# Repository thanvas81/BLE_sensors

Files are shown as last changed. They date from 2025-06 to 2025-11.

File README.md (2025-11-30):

BLE Sensor PCB – Project Repository

This repository contains all design files, documentation, and supporting materials for my BLE Sensor PCB Thesis.
It includes the hardware schematics, PCB layout, some example firmware, datasheets, and the final report/presentation.

📁 Repository Contents
🔧 BLE_sensors_pcb/

This folder contains the complete PCB design files, including:

Schematic

Board layout

These files represent the final hardware design for the BLE sensor module.

🧠 firmware/

This folder includes the early firmware code used to run the BLE sensor system.

📄 pdf_and_presentation/

This folder contains the final project documentation, including:

Project pdf

Slides / presentation

Thesis or final written report

This is the main reference for understanding the project goals, design, testing, and results.

📚 Datasheets/

Supporting datasheets for components used in the PCB design.

⚙️ .vscode/

Editor and workspace configuration files (for VS Code).

📘 Overview

This project focuses on developing a custom Bluetooth Low Energy sensor board for Indoor Tracking, including hardware design, embedded firmware, and full documentation of the development process.
The PCB, firmware, and final report together demonstrate the complete lifecycle of the system.

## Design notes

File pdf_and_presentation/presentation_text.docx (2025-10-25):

### Slide 1 — Cover

Καλημέρα σας, είμαι ο Βασίλογλου Αθανάσιος και σήμερα θα παρουσιάσω τη διπλωματική μου εργασία με τίτλο «Design of a Wireless Indoor Tracking System for Multi-Sensor Data Acquisition with BLE Channel Sounding», η οποία εκπονήθηκε στο ΕΜΠ υπό την επίβλεψη του καθηγητή κ. Χριστοφόρου.

### Slide 2 — Introduction (empty template in PPT, narrative needed)

Η ιδέα για την εν λόγω διπλωματική προέκυψε από ένα προβλημα που παρατήρησα καθημερινά στην δουλειά μου . Εργάζομαι στη BK Telematics σε μια εταιρεια η οποια ασχολείται κυρίως με συσκευές τηλεματικής επιτήρησης στόλου. Στην πράξη βλέπω καθημερινά ότι ενώ τα GPS/GNSS συστήματα λειτουργούν εξαιρετικά σε εξωτερικούς χώρους, καταρρέουν αμέσως μόλις βρεθούμε σε εσωτερικούς χώρους — είτε λόγω πλήρους απώλειας σήματος είτε λόγω έντονου multipath που οδηγεί σε δραματικά σφάλματα. Από αυτή τη διαπίστωση προήλθε και η ιδέα της εργασίας: να δημιουργήθεί μια λύση αντίστοιχης πρακτικότητας, αλλά λειτουργική σε indoor περιβάλλον. Στο πλαίσιο αυτό ανέπτυξα ένα χαμηλού κόστους και ενεργειακά αποδοτικό σύστημα που συνδυάζει indoor localization με multi-sensor data acquisition. Επελεξα BLE διότι είναι ήδη ευρέως διαθέσιμο, έχει χαμηλή κατανάλωση και με την εισαγωγή του Channel Sounding δίνει πρόσβαση σε( In-phase and quadrature) IQ-based μετρήσεις που επιτρέπουν sub-meter ακρίβεια χωρίς ειδικό hardware όπως άλλες γνωστές λύσεις πχ Ulta Wide band. Παράλληλα ενσωματώνονται περιβαλλοντικοί αισθητήρες και IMU ώστε ο κόμβος να μην είναι απλώς position tag αλλά context-aware monitoring μονάδα η οποία μπορεί να αξιοποιηθεί και ως ένα μέτρο ασφάλειας στον τομέα του industrial monitoring.

### Slide 3 — BLE Positioning Approaches

Οι BLE τεχνικές εντοπισμού μπορούν να ομαδοποιηθούν σε τρεις βασικές προσεγγίσεις.
Πρώτον, το RSSI-based localization, όπου η απόσταση εκτιμάται από τη στάθμη ισχύος του λαμβανόμενου σήματος. Είναι η απλούστερη μέθοδος, αλλά επηρεάζεται έντονα από multipath φαινόμενα με αποτέλεσμα περιορισμένη ακρίβεια με σφάλματα της τάξεως περίπου των 5 μέτρων . Δεύτερον, η μέθοδος AoA/AoD (Angle of Arrival/Departure), κατά την οποία χρησιμοποιούνται antenna arrays για να εξαχθεί η κατεύθυνση του σήματος. Η μέθοδος αυτή μπορεί να βελτιώσει σημαντικά την γεωμετρική επίλυση της θέσης ρίχνοντας την ακρίβεια περίπου στο 1 μέτρο , αλλά απαιτεί σύνθετο και ακριβό hardware. Η τελευταία μέθοδος είναι η χρήση του Channel Sounding, το οποίο εκμεταλλεύεται IQ-based μετρήσεις μέσω της ανακατασκευής της κρουστικης απόκρυσης του inverse fast fourier transform (IFFT) και μέσω Phase-Based Ranging .Με αυτους τους τρόπους η μέθοδος του chanel sounding καταφέρνει ναι εξαχθεί η απόσταση με sub-meter ακρίβεια, χωρίς την ανάγκη για array antennas. Στην παρούσα εργασία επιλέγεται η τρίτη προσέγγιση, επειδή προσφέρει τον καλύτερο συμβιβασμό ανάμεσα σε ακρίβεια και υλοποιήσιμη πολυπλοκότητα. Πάμε να αναλύσουμε εκτενέστες τους τρόπους υπολογισμού της απόστασης

### Slide 4 — IFFT Based Ranging

Στην περίπτωση του IFFT based ranging αξιοποιούμε το γεγονός ότι το κανάλι μετριέται σε διακριτές συχνότητες. Η κρουστική απόκριση αποτυπώνει τη χρονική δομή των πολλαπλών διαδρομών του σήματος καθως το σήμα φτάνει πολλαπλές φορές με διαφορετικές καθυστερήσεις και εντάσεις λόγω ανακλάσεων, σκέδασης κλπ. Η βασική ιδέα της μεθόδου είναι ότι το πρώτο ισχυρό peak στην κρουστικη αποκρυση CIR αντιστοιχεί στη συντομότερη φυσική διαδρομή – συνήθως την Line-of-Sight. Από τη χρονική καθυστέρηση τ του πρώτου peak εξάγουμε την απόσταση με d=c⋅τ,. Είναι σημαντικό να τονίσουμε ότι το resolution εξαρτάται από το συνολικό bandwidth και άρα σε BLE, που είναι narrowband, υπάρχει intrinsic limit στην χρονική διακριτική ικανότητα. Ωστόσο, σε περιβάλλον με LOS ή ήπιο multipath, η μέθοδος παραμένει σταθερή και χαμηλής διασποράς, κάτι που επιβεβαιώνεται στα πειραματικά αποτελέσματα αργότερα.

((

Όταν μετράς το κανάλι σε λίγο bandwidth, βλέπεις μόνο ένα “χοντρό” κομμάτι του φάσματος. Όταν κάνεις IFFT αυτού του περιορισμένου φάσματος, το αποτέλεσμα στο χρόνο είναι φαρδύ και δεν μπορείς να ξεχωρίσεις πολύ κοντινά multipath peaks — “μπερδεύονται” μεταξύ τους.

Με μεγάλο bandwidth έχεις πιο “λεπτομερή” γνώση του καναλιού στο frequency domain, άρα στο χρονικό domain η CIR γίνεται πιο αιχμηρή (με στενά peaks) και μπορείς να διακρίνεις πιο μικρές χρονικές διαφορές.

))

### Slide 5 — Phase Based Ranging

Στη περίπτωση του Phase-Based Ranging εκτιμούμε την απόσταση από το phase response του καναλιού στο πεδιο της συχνότητας. Ουσιαστικά η φάση ακολουθεί μια γραμμική σχέση με τη συχνότητα (της μορφής ϕ(f) ≈ −2πfd/c + ϕ0), και επομένως η κλίση αυτής της γραμμικής σχεσης μάς αποκαλύπτει την απόσταση. Το βασικό μειονέκτημα στην αντιμετώπιση της φάσης είναι ότι η μετρούμενη φάση είναι 2π wraping, δηλαδή το σύστημα “βλέπει” μόνο την υπόλοιπη τιμή μετά από κύλιση. Αυτό εισάγει αμφιβολια στον υπολογισμο της αποστασης γιατί πολλές διαφορετικές πραγματικές αποστάσεις δίνουν την ίδια τυλιγμένη φάση. Για να αρθεί αυτό το προβλημα αξιοποιείται multifrequency fitting: μετράμε δηαλδη τη φάση σε πολλαπλές συχνότητες και αναζητούμε τη γραμμική κλίση που εξηγεί με συνέπεια όλα τα wrapped δείγματα ταυτοχρόνως. Στην πράξη αυτό σημαίνει ότι εξετάζουμε όλες τις δυνατές “ξετυλιγμένες” εκδοχές (phase unwrapping hypotheses) για κάθε συχνότητα και βρίσκουμε εκείνη τη συνεπή λύση της μορφής που ελαχιστοποιεί το συνολικό σφάλμα fitting. Η ύπαρξη πολλαπλών συχνοτήτων σπάει το ambiguity που θα υπήρχε αν κοιτούσαμε μόνο μία συχνότητα, επειδή οι λάθος “λύσεις” δεν μπορούν να ευθυγραμμιστούν ταυτοχρόνως με γραμμική τάση σε όλο το σύνολο συχνοτήτων, ενώ η σωστή απόσταση παράγει συνεπή κλίση σε όλα τα σεναρια . Παρόλο που η μέθοδος είναι περισσότερο ευαίσθητη στο multipath σε σχέση με την IFFT, προσφέρει υψηλότερη θεωρητική ακρίβεια σε short-range σενάρια με καλή SNR και σταθερή φάση,

### Slide 6 — Hardware Design (Section title slide)

Σε αυτό το σημείο περνάμε από το θεωρητικό υπόβαθρο στην υλοποίηση. Το σύστημα που αναπτύχθηκε ενσωματώνει MCU με υποστήριξη BLE 6.0 αρα και Channel Sounding, υποσύστημα αισθητήρων, power management, και ενσύρματη διεπαφή UART–USB για debugging και data export. Η υλοποίηση έγινε σε 4-layer PCB με στόχο RF σταθερότητα, χαμηλό θόρυβο τοσο σε σήματα όσο και σε τροφοδοσία και συμπαγές αποτύπωμα, ώστε η σχεδίαση να είναι μεταφέρσιμη σε πραγματικές εφαρμογές και όχι απλώς εργαστηριακό πρωτότυπο.

### Slide 7 — PCB Stack Up

Eδώ παρατηρούμε το stack-up του PCB, στο οποίο το πρώτο inner layer λειτουργεί ως συνεχές ground plane για RF σταθερότητα και ελαχιστοποίηση επιστροφών, ενώ το δεύτερο inner layer χρησιμοποιείται ως dedicated power plane για τις 3V3 και 5V γραμμές. Τα εξωτερικά layers χρησιμοποιούνται για routing υψηλής πυκνότητας και τοποθέτηση εξαρτημάτων, με προσοχή στην τήρηση αποστάσεων από την RF περιοχή γύρω από το module. Επιπλέον, ο σχεδιασμός των σημάτων υψηλής ταχύτητας έγινε με καθαρές γραμμές (straight/continuous routing), αποφυγή περιττών vias και length/impedance matching στη διαφορική γραμμή USB ώστε να διατηρούνται οι προδιαγραφές signal integrity. Η εν λόγω δομή μειώνει τα ground discontinuities, περιορίζει EMI/EMC φαινόμενα και επιτρέπει αξιόπιστη λειτουργία υπό παρουσία έντονων χρονιστικών μεταβάσεων.

### Slide 8 — Schematic Diagram

Περνώντας στο πλήρες σχηματικό φαίνεται η ενσωμάτωση πέντε βασικών υποσυστημάτων: του ME54BS01 module με τον nRF54L15, του power subsystem (charger + buck-boost), των αισθητήρων (BME280 και IMU), του UART–USB bridge για διασύνδεση με host και των header για debug/flash. Στο επίπεδο του schematic δόθηκε έμφαση σε καθαρό διαχωρισμό των σήματων και σωστή αποσύζευξη στα κρίσιμα σημεία, ώστε να προετοιμαστεί ο layout χωρίς αλληλεπιδράσεις με το RF κομματι .

### Slide 9 — Power Supply (Part 1 — Battery & Charger)

Το power supply επιτρέπει διπλή τροφοδοσία — είτε από USB Type-C είτε από Li-ion μπαταρία. Ο charger (MCP73871 )αναλαμβάνει το charging με power-path management, διασφαλίζοντας ότι το σύστημα τροφοδοτείται ακόμη και κατά τη φόρτιση. Η διαχείριση αυτή είναι κρίσιμη καθώς μας επιτρέπει αδιάκοπη λειτουργία. Επιπλέον, δίνονται επιλογές θερμικής προστασίας και ρυθμιζόμενα charging profiles ώστε το subsystem να είναι robust στα πραγματικά deployment περιβάλλοντα.

Στο δεύτερο μέρος του power subsystem χρησιμοποιείται buck–boost converter (TPS63031) ώστε να παρέχεται σταθερά 3.3V ανεξάρτητα από το αν η είσοδος προέρχεται από USB στα 5V ή από Li-ion μπαταρία οπου κυμαίνεται 3.0–4.2V. Αυτό επιτρέπει αδιάλειπτη λειτουργία ακόμη και σε μεταβάσεις τροφοδοσίας. Εφαρμόστηκαν και decoupling πυκνωτές κοντά στις εισόδους/εξόδους για περιορισμό ripple. Η δομή με ξεχωριστά blocks (charger + regulator) δίνει modularity και, κυρίως, σαφή έλεγχο συμπεριφοράς σε κάθε “βημα¨ της τροφοδοσίας

### Slide 11 — UART – USB Bridge

Περνώντας στη uart usb bridge οπου χρησιοποιηθηκε κυρίως ως gateway για την ανάκτηση των δεδομέων περιβάλοντως και απόστασης βέπουμε πως χρησιμοποιήθηκε το MCP2221A που μεταφράζει UART frames σε USB αναγνωρίσιμο ως ένα virtual COM από το PC. Ο USB-C connector υλοποιήθηκε με CC biasing, ESD protection για προστασία. Η λύση αυτή επιτρέπει αξιόπιστο debug/logging και ταυτόχρονα διοχέτευση μετρήσεων χωρίς εξαρτήσεις από BLE,οποτε έχουμε ένα out-of-band αξιόπιστο control & export path.Ας περάσουμε τώρα στην υλοποίηση του λογισμικου.

### Slide 12 — Firmware Reflector (Flowchart)

Ξεκινώντας με το Το firmware του Reflector node βλέπουμε πως έχει κρατηθεί μια ξεκάθαρη δομήμε 3 task : αρχικά κανει ένα initialization των περιφερειακών και των αισθητήρων, και στη συνέχεια ππερνάει σε μια κατασταης αναμονής για Channel Sounding requests που προέρχονται από τον Initiator, αν λάβει μήνυμα εκίνηςης ξεκινά να «απανταει» πισω τα απαρίτητα μυνηματα για τον υπολογισμό της απόστασης στην μεριά του initiator . Παράλληλα εκτελεί περιοδικές μετρήσεις από BME280 και την τάση της μπαταρίας , τις τυποποιεί σε ένα sting μαζι με το id του reflector και τις δημοσιεύει μέσω BLE connectionless advertising. Η χρήση conection less advertising αντί σύνδεσης μειώνει latency και ενέργεια, επιτρέποντας scalable reception από πολλαπλούς anchors. Παράλλη έχει υλοποιηθεί μια ρουτίνα ελέγχου από την τελευταία κίνηση κατά την οποία αν περάσει ένα χρονικό διάσημα αδράνειας θέτει την συσκευή σε sleep mode για βελτιστη κατανάλωση ενεργιας

### Slide 13 — Initiator Firmware (Flowchart)

Ο Initiator είναι ο κόμβος που ελέγχει ενεργά την Channel Sounding διαδικασία. Ξεκινά με initialization Bluetooth stack και UART, και στη συνέχεια εκτελεί περιοδικά ranging sessions στέλνοντας καποαι ειδικά packets προς τον Reflector. Από την ανταλλαγή αυτή λαμβάνει IQ data και επεξεργάζεται σε πραγματικό χρόνο τα αποτελέσματα IFFT και Phase-Based Ranging για να εξάγει απόσταση. Ταυτόχρονα λειτουργεί ως gateway: λαμβάνοντας τα BLE advertisements από τον Reflector και προωθοντας τα μέσω UART στο host για logging και offline ανάλυση. Αυτή η αρχιτεκτονική απομονώνει τον υπολογισμό από τον φορητό κόμβο και κρατά τον Initiator ως σταθερό σημείο υψηλής αξιοπιστίας. Ας δούμε τωρα τα πειράματα και τα αποτελέσματα που εξάγαμε .

### Slide 14 — Results — First Testing Setup

Το πρώτο experimental setup αφορά ένα stepped–distance measurement σε ελεγχόμενο διάδρομο, ώστε να εξαχθεί ένα baseline error behavior των δύο μεθόδων (IFFT και Phase-Based Ranging). Σε κάθε βήμα κρατήθηκε σταθερή απόσταση και καταγράφηκαν πολλαπλές μετρήσεις για να εξαγουμε το average error.Το setup προσομοιώνει ρεαλιστική indoor LOS διάταξη, όπου multipath υπάρχει, αλλά όχι σε ακραίο βαθμό, επιτρέποντας καθαρή σύγκριση αλγορίθμων χωρίς υπερβολική παρεμβολή.Παρατηρούμε ότι σε αν δεν δεν υπήρξε έντονο mulitpath το PBR κατέληξε σε σημαντικά μεγαλύτερο error για αυτό για τις επόμενες μετρήσεις προτιμήθηκε η προσοχή να παραμείνει σον IFFT τροπο μετρησης. Παράληλα συνέχισα να λαμβάνω τα δεδομένα pbr με ανάλογο σφλαμα

### Slide 15 — Results — Second Testing Setup

Στο δεύτερο setup δοκιμάζεται μία πιο σύνθετη διάταξη one–initiator/one–reflector σε 2.7 m απόσταση, τοποθετημένα εκατέρωθεν διαδρόμου. Εδώ αξιολογείσα τη συμπεριφορά σε μεσαία απόσταση με πραγματικό multipath από τοίχους και πάτωμα καθως και τον εισαγώμενο θόρυβο λογο τις κίνησης ανθρωπων στον διάδρομο. Ο σκοπός δεν είναι μόνο το absolute error αλλά και η σταθερότητα στο χρόνο — δηλαδή πόσο “τρέμει” η εκτίμηση σε σταθερό geometry.Τα αποτελέσματα και πάλι μας έδωσαν πολύ χαμηλό estimation erro και σταθερό ως προς τον χρόνο και το ενναλασώμενο περιβάλλον

### Slide 16 — Results — Third Testing Setup

Στο τρίτο setup εξετάζεται πιο ρεαλιστικό περιβάλλον με ποικιλία αντικειμένων( ο χωρος ήταν κανονικά γεμάτος ) και αυξημένη ανακλαστικότητα, όπου το multipath γίνεται εντονότερο και στο εν λόγω παράδειγμα εξετάστικε και η ικανότητα του reflector να ανταπεξέλθει στα αιτήματα τριων initiator ταυτοχρονα . Το experiment αυτό δείχνει την συμπεριφορά του συστήματος σε ένα ρεαλιστικό περιβάλλον με διάφορους θορύβους και συνεχόμενη κίνηση ανθρωπων για να λάβουμε κάποια αποτελέσματα σε πιο ένα «ρεαλιστικό σενάριο» .

### Slide 17 — Results — Error Heat Map

Εδώ παρουσιάζεται ένα heat map του τοπικού error field γύρω από target περιοχή σε 1×1 m παράθυρο , με τα anchors σε σταθερή διάταξη. Το heat map αποκαλύπτει χωρική κατανομή σφάλματος, δείχνοντας ότι ο υπολογισμός της απόστασης παραμένει σε πολύ χαμηλά επίπεδα σφάλματος παρόλο την ταυτόχρονη εκτίμηση τριών initiator κρατώντατ το error σε επίπεδα κάτω των 0,2 μετρων

### Slide 18 — Conclusions and Perspectives

Συνολικά, αποδείχθηκε ότι το BLE Channel Sounding με IFFT-based εξαγωγή απόστασης μπορεί να επιτύχει sub-meter ακρίβεια σε indoor περιβάλλον χωρίς ειδικό hardware πέρα από BLE 6-ready modules, ενώ το Phase-Based Ranging λειτουργεί συμπληρωματικά αλλά είναι πιο ευαίσθητο και σε ένα θορυβόδες περιβάλλον η ακρίβεια του παραμένει κοντα στο ένα μετρο και λιγο απραπανω . Το σύστημα είναι modular, low-cost(15 ευρω ) και επιτρέπει κλιμάκωση προς multi-anchor positioning. Μελλοντικά, η εξέλιξη του project περιλαμβάνει (i) ανάπτυξη real-time supervision software, (ii) την μεταφορά σε ένα πιο scalable wireless gateway για συλλογή και διάθεση δεδομένων, , (iii) σχεδίαση στοχευμένου anchor/initiator hardware με ενίσχυση RF (βελτιστοποιημένη κεραία, PA/LNA front-end και dedicated RF layout) για μεγιστοποίηση εμβέλειας,καθως και στην περιπτωση που χρειαστει ένα πλήρως energy efficient μοντελο φια τον reflector αφαιρώντας κάποια στοιχεια όπως κάποια led , uart bridge κλτπ και τελευταιο θα μπορούσε να γίνει επέκταση των πειραμάτων προσθέτωντας έναν τέταρτο inititor γθα πλήρες 3D localization.

### Slide 19 — Thank you

Ευχαριστώ πολύ για τον χρόνο σας.

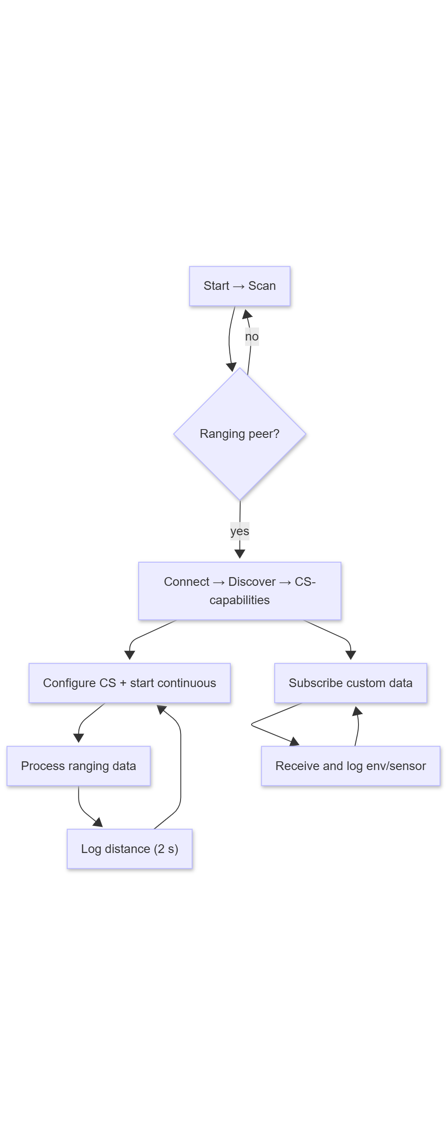
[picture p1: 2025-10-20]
pdf_and_presentation/ranging_data_logging.png

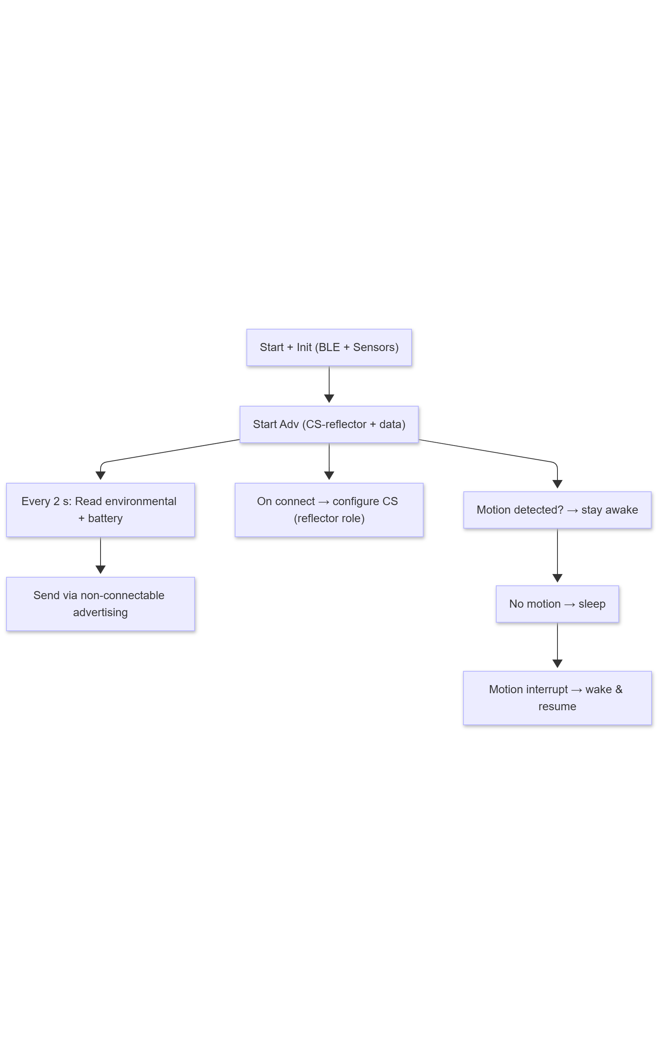
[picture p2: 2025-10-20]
pdf_and_presentation/ble_sensor_advertising.png

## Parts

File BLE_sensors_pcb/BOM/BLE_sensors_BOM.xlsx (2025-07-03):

Reference | Qty | Value | Footprint | Ordered | Status
C1, C2, C3, C4, C6, C11, C14, C16 | 8 | 0.1u | Capacitor_SMD:C_0603_1608Metric
C5, C10, C12, C13 | 4 | 10u | Capacitor_SMD:C_0805_2012Metric
C7, C8 | 2 | 4.7u | Capacitor_SMD:C_0603_1608Metric
C9 | 1 | 10u | Capacitor_SMD:C_0603_1608Metric
C17 | 1 | 4.7u | Capacitor_SMD:C_0805_2012Metric
D1, D2, D3 | 3 | LED | LED_SMD:LED_0603_1608Metric | OK
D4 | 1 | PRTR5V0U2X | Package_TO_SOT_SMD:SOT-143 | OK
J2 | 1 | Conn_01x02 | Connector_PinHeader_1.27mm:PinHeader_1x02_P1.27mm_Vertical
J3 | 1 | USB_C_Receptacle | Connector_USB:USB_C_Receptacle_G-Switch_GT-USB-7010ASV | GT-USB-7010ASV ?
L1 | 1 | 1.5u | Inductor_SMD:L_1210_3225Metric
R1, R2 | 2 | 4.7k | Resistor_SMD:R_0603_1608Metric
R3 | 1 | Rprog1 | Resistor_SMD:R_0603_1608Metric
R4 | 1 | Rprog3 | Resistor_SMD:R_0603_1608Metric
R5, R6, R7 | 3 | 470R | Resistor_SMD:R_0603_1608Metric
R8, R9 | 2 | 22R | Resistor_SMD:R_0603_1608Metric
R10, R14 | 2 | 100k | Resistor_SMD:R_0603_1608Metric
R11, R12 | 2 | 5.11k | Resistor_SMD:R_0603_1608Metric
R13 | 1 | 1M | Resistor_SMD:R_0603_1608Metric
R15, R16 | 2 | 100R | Resistor_SMD:R_0603_1608Metric
R17, R18, R19, TH1 | 4 | 10k | Resistor_SMD:R_0603_1608Metric
U1 | 1 | BME280 | Package_LGA:Bosch_LGA-8_2.5x2.5mm_P0.65mm_ClockwisePinNumbering | OK
U2 | 1 | LSM303AHTR | My_Libraries:LSM303AHTR | OK
U3 | 1 | TPS63031DSK | Package_SON:WSON-10-1EP_2.5x2.5mm_P0.5mm_EP1.2x2mm | OK
U4 | 1 | ME54BS01 | My_Libraries:ME54BS01 | OK | OK
U5 | 1 | MCP73871 | Package_DFN_QFN:QFN-20-1EP_4x4mm_P0.5mm_EP2.5x2.5mm | OK
U7 | 1 | MCP2221AxST | Package_SO:TSSOP-14_4.4x5mm_P0.65mm | ΟΚ

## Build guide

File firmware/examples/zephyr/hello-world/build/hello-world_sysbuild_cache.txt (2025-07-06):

APPLICATION_BINARY_DIR:PATH=C:/Users/Asus/Desktop/Files/School/Thesis/blecon-device-sdk/examples/zephyr/hello-world/build
APPLICATION_SOURCE_DIR:PATH=C:/ncs/v2.9.1/zephyr/share/sysbuild/template
APP_DIR:PATH=c:/Users/Asus/Desktop/Files/School/Thesis/blecon-device-sdk/examples/zephyr/hello-world
BOARD_DIR:PATH=C:/Users/Asus/Desktop/Files/School/Thesis/blecon-device-sdk/examples/zephyr/boards/minew/minew_me54be01/boards/minew/minew_me54be01
BOARD_DIRECTORIES:INTERNAL=C:/Users/Asus/Desktop/Files/School/Thesis/blecon-device-sdk/examples/zephyr/boards/minew/minew_me54be01/boards/minew/minew_me54be01
BOARD_EXTENSIONS:BOOL=ON
BOARD_ROOT:PATH=C:/Users/Asus/Desktop/Files/School/Thesis/blecon-device-sdk/examples/zephyr/boards/minew/minew_me54be01;C:/test/blinky_pwm
CACHED_BOARD:STRING=minew_me54be01/nrf54l15/cpuapp
CACHED_SHIELD:STRING=
FIND_PACKAGE_MESSAGE_DETAILS_Python3:INTERNAL=[C:/ncs/toolchains/0b393f9e1b/opt/bin/python.exe][cfound components: Interpreter ][v3.12.4(3.8)]
HWM:INTERNAL=v2
HWMv2:INTERNAL=True
NCS_TOOLCHAIN_VERSION:UNINITIALIZED=NONE
WEST:INTERNAL=C:/ncs/toolchains/0b393f9e1b/opt/bin/python.exe;-m;west
WEST_PYTHON:UNINITIALIZED=C:/ncs/toolchains/0b393f9e1b/opt/bin/python.exe
ZEPHYR_BASE:PATH=C:/ncs/v2.9.1/zephyr
Zephyr_DIR:PATH=C:/ncs/v2.9.1/zephyr/share/zephyr-package/cmake
_Python3_EXECUTABLE:INTERNAL=C:/ncs/toolchains/0b393f9e1b/opt/bin/python.exe
_Python3_INTERPRETER_PROPERTIES:INTERNAL=Python;3;12;4;64;;cp312-win_amd64;C:\ncs\toolchains\0b393f9e1b\opt\bin\Lib;C:\ncs\toolchains\0b393f9e1b\opt\bin\Lib;C:\ncs\toolchains\0b393f9e1b\opt\bin\Lib\site-packages;C:\ncs\toolchains\0b393f9e1b\opt\bin\Lib\site-packages
_Python3_INTERPRETER_SIGNATURE:INTERNAL=789456af6c61fc011023bd90a8135e32
sysbuild_toplevel_BINARY_DIR:STATIC=C:/Users/Asus/Desktop/Files/School/Thesis/blecon-device-sdk/examples/zephyr/hello-world/build
sysbuild_toplevel_IS_TOP_LEVEL:STATIC=ON
sysbuild_toplevel_SOURCE_DIR:STATIC=C:/ncs/v2.9.1/zephyr/share/sysbuild
BOARD:STRING=minew_me54be01/nrf54l15/cpuapp
SYSBUILD_NAME:STRING=hello-world
SYSBUILD_MAIN_APP:BOOL=True

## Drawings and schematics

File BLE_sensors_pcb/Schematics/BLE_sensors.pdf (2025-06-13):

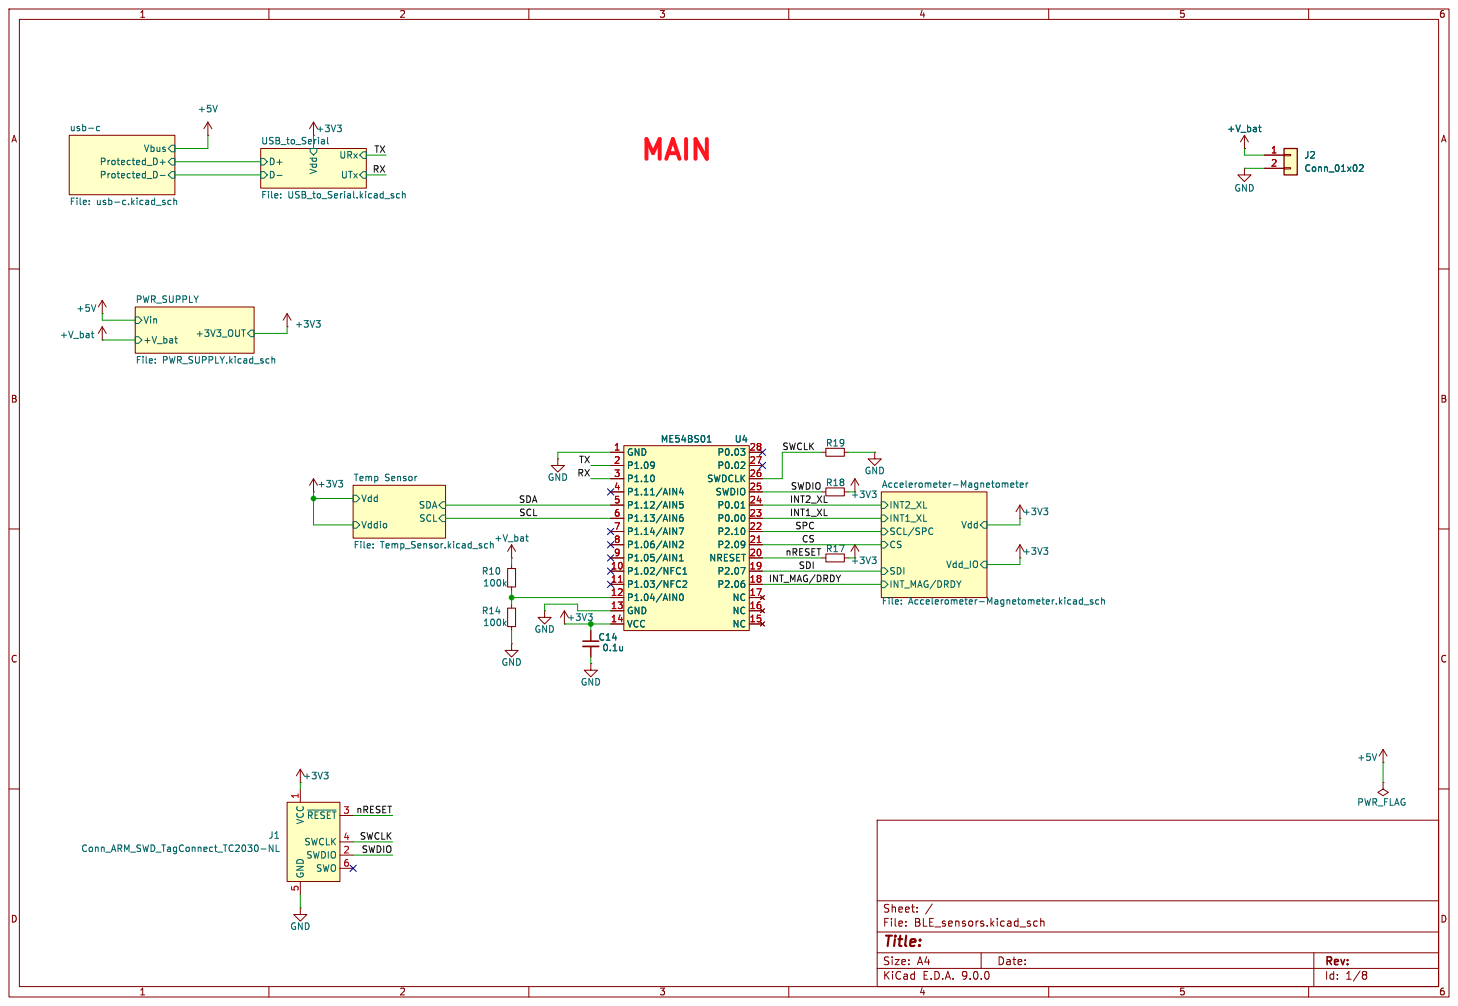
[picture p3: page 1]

Accelerometer-Magnetometer File: Accelerometer-Magnetometer.kicad_sch GND

5 ~{RESET}3 SWCLK 4 SWDIO 2 SWO 6

Id: 1/8 Title: File: BLE_sensors.kicad_sch Sheet: /

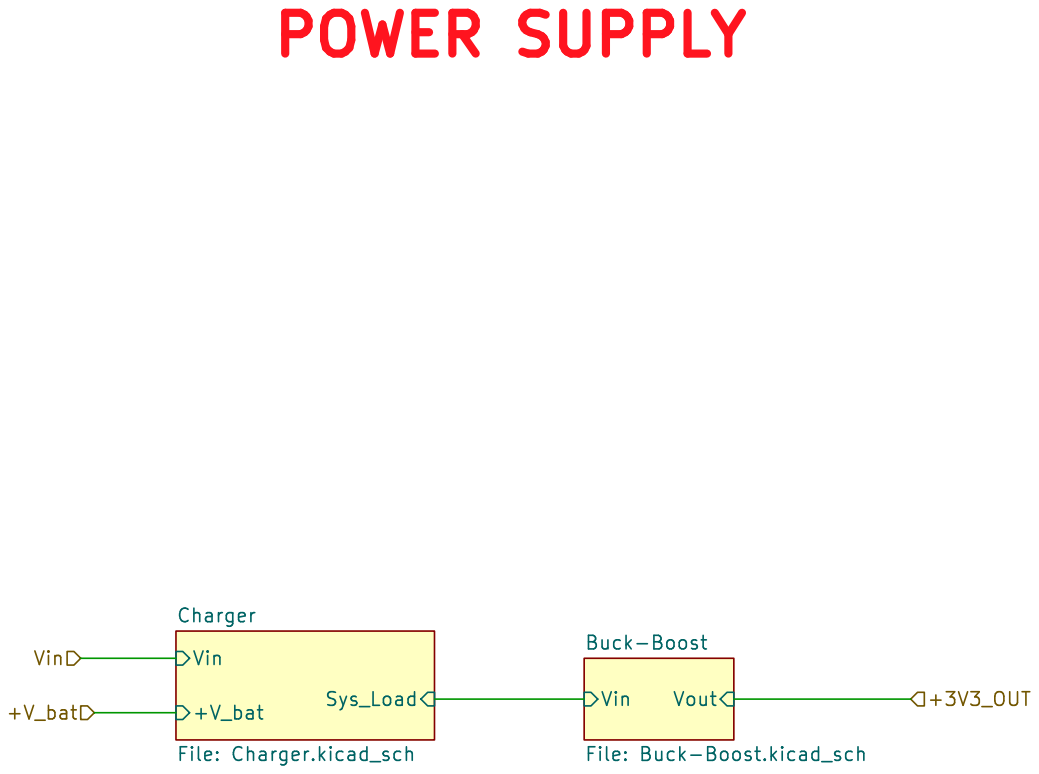
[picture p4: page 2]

Id: 2/8 Title: Charger File: PWR_SUPPLY.kicad_sch Sheet: /PWR_SUPPLY/

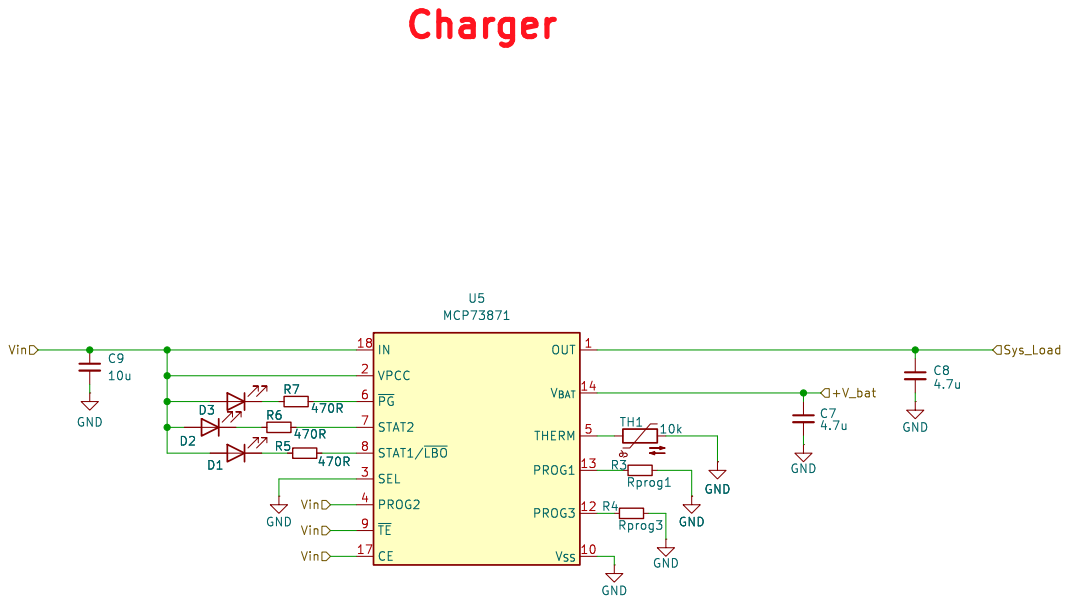
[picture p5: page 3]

Id: 3/8 Title: Charger File: Charger.kicad_sch Sheet: /PWR_SUPPLY/Charger/

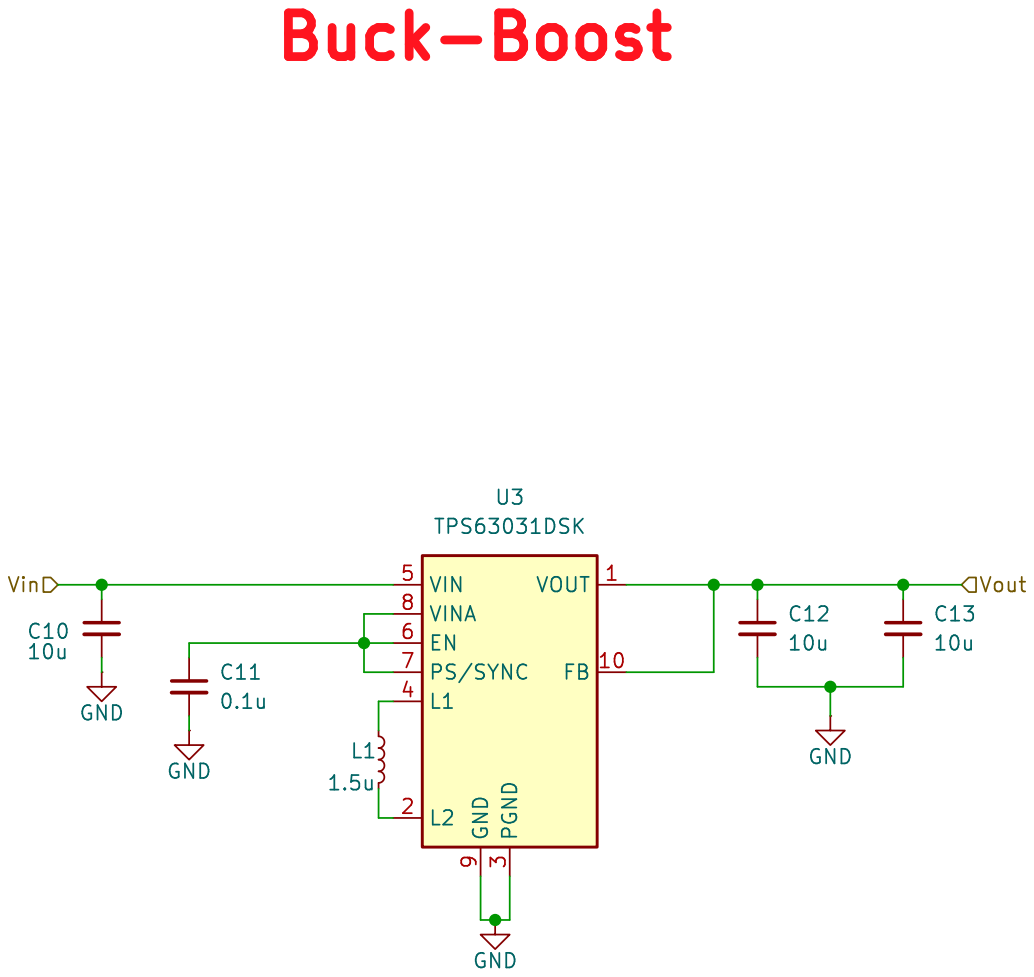
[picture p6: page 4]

Id: 4/8 Title: File: Buck-Boost.kicad_sch Sheet: /PWR_SUPPLY/Buck-Boost/

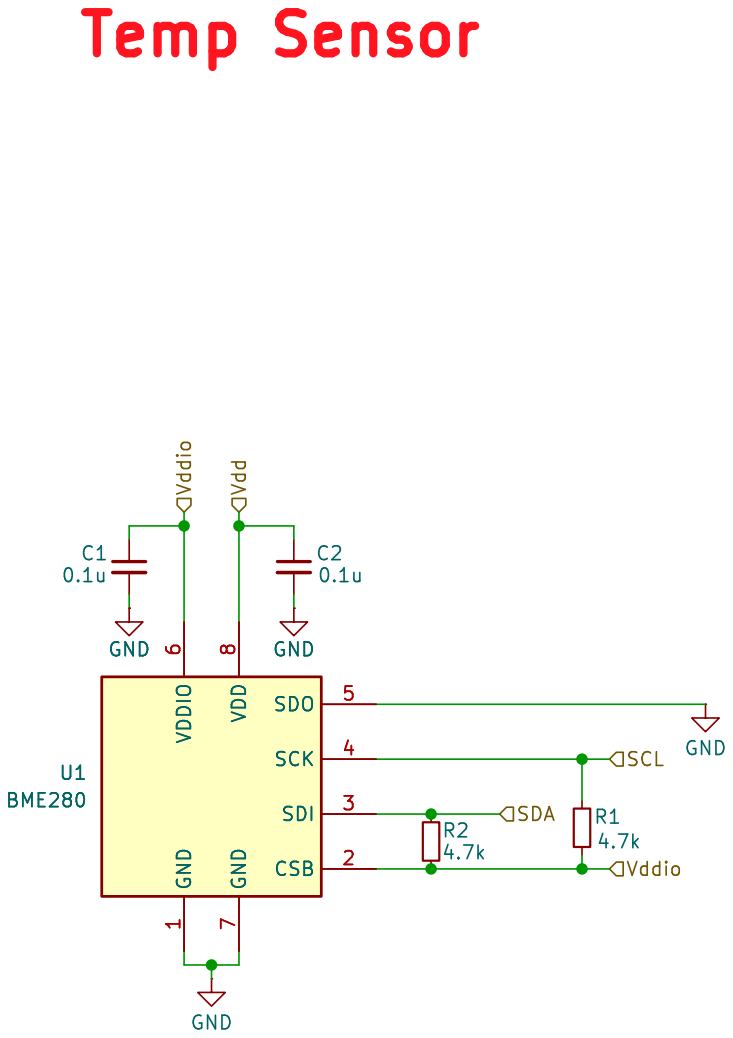
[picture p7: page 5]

7 SDO 5 SCK 4 SDI 3 CSB 2 U1 BME280 C2
0.1u GND

7 SDO 5 SCK 4 SDI 3 CSB 2 GND GND
4.7k VDDIO

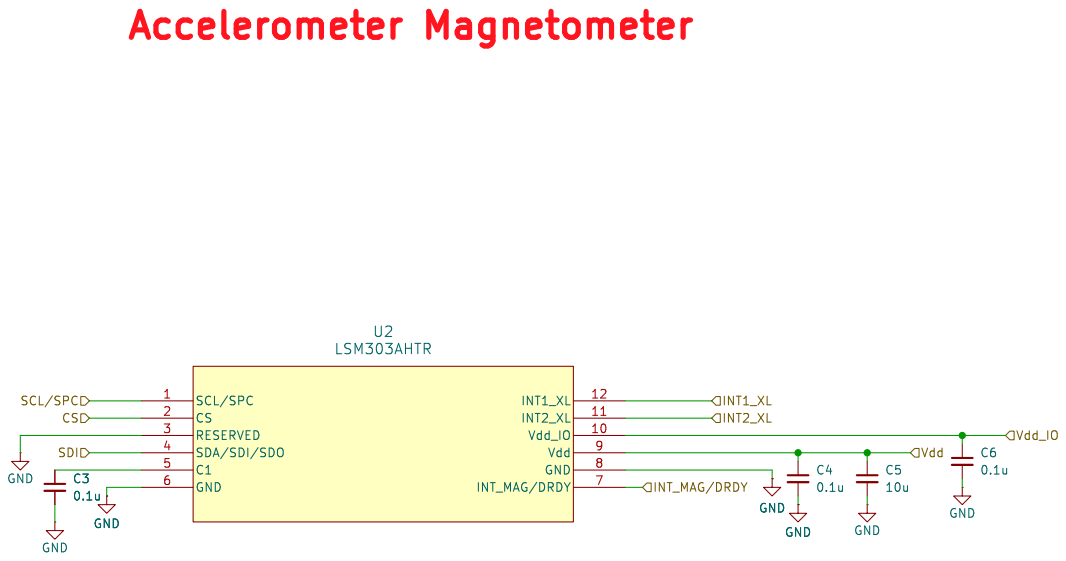
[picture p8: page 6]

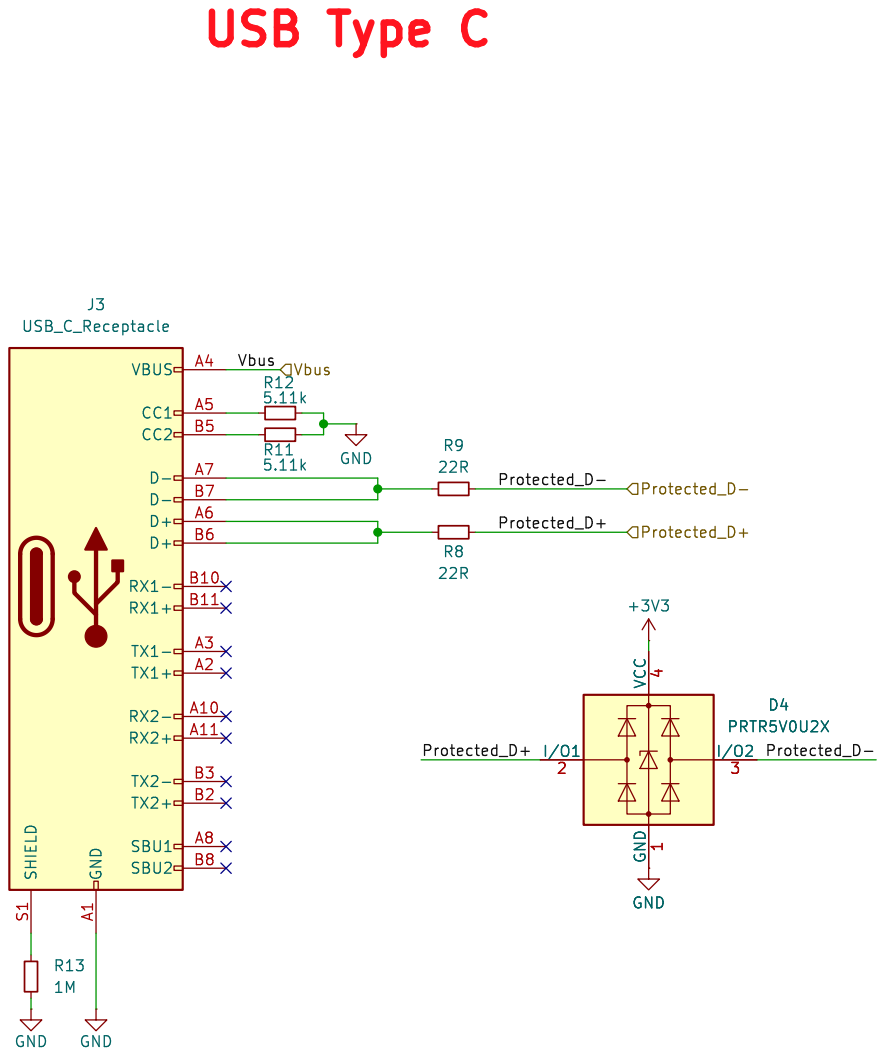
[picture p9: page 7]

Id: 8/8 Title: File: usb-c.kicad_sch Sheet: /usb-c/

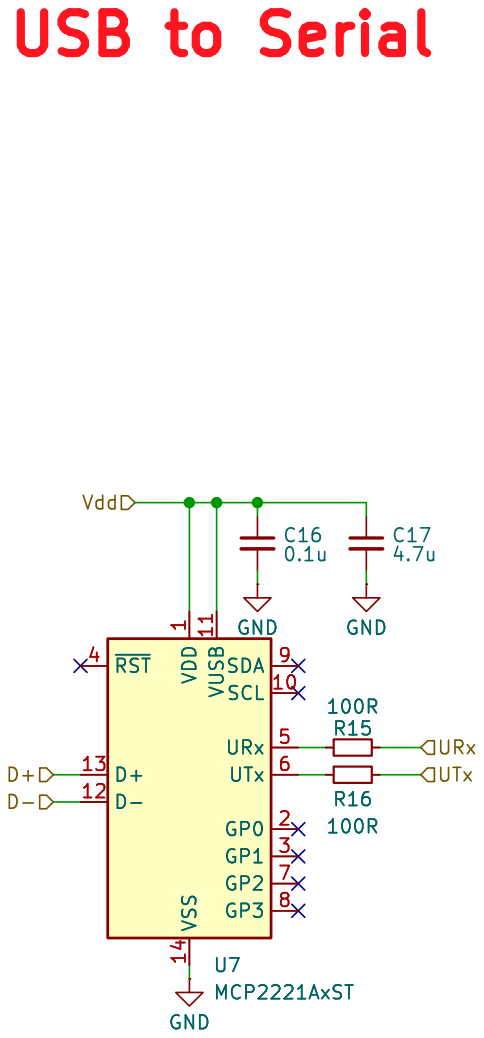
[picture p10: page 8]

1 VSS 14 VUSB 11 SDA 9 SCL 10 URx 5 UTx 6 GP0 2 GP1 3 GP2 7 GP3 8 U7 MCP2221AxST C17
0.1u GND GND

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

Id: 9/8 Title: File: USB_to_Serial.kicad_sch Sheet: /USB_to_Serial/

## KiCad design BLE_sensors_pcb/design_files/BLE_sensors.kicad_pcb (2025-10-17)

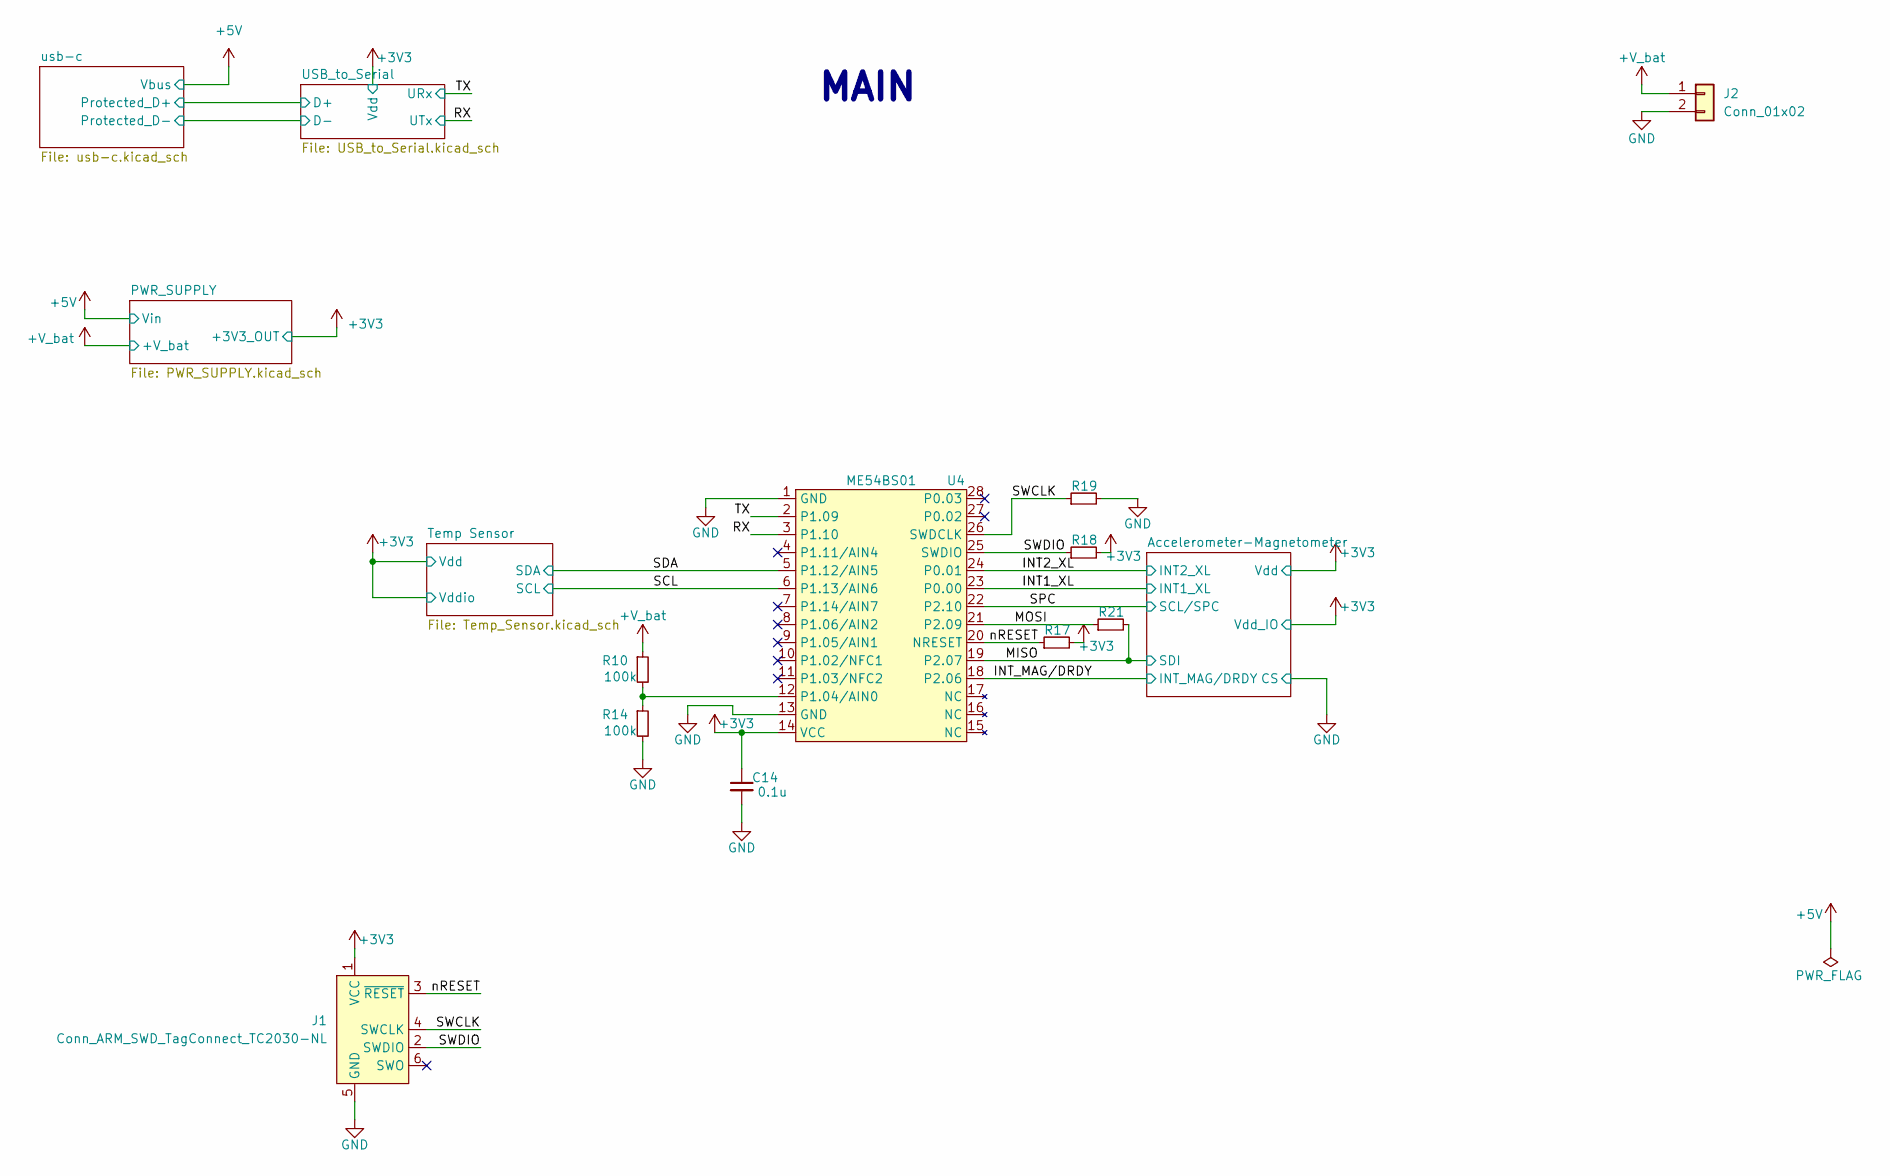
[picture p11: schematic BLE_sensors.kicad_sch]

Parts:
C14: 0.1u; C_0603_1608Metric
J1: Conn_ARM_SWD_TagConnect_TC2030-NL; Tag-Connect_TC2030-IDC-NL_2x03_P1.27mm_Vertical
J2: Conn_01x02; PinHeader_1x02_P1.27mm_Vertical
R10, R14: 100k; R_0603_1608Metric
R17, R18, R19, R21: 10k; R_0603_1608Metric
U4: ME54BS01

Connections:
+3V3: C14.1, J1.1 (VCC), R17.2, R18.2, U4.14 (VCC); also elsewhere on the board
+V_bat: J2.1, R10.1; also elsewhere on the board
/INT1_XL: U4.23 (P0.00); also elsewhere on the board
/INT2_XL: U4.24 (P0.01); also elsewhere on the board
/INT_MAG/DRDY: U4.18 (P2.06); also elsewhere on the board
/MISO: R21.2, U4.19 (P2.07); also elsewhere on the board
/MOSI: R21.1, U4.21 (P2.09)
/RX: U4.3 (P1.10); also elsewhere on the board
/SCL: U4.6 (P1.13/AIN6); also elsewhere on the board
/SDA: U4.5 (P1.12/AIN5); also elsewhere on the board
/SPC: U4.22 (P2.10); also elsewhere on the board
/SWCLK: J1.4 (SWCLK), R19.1, U4.26 (SWDCLK)
/SWDIO: J1.2 (SWDIO), R18.1, U4.25 (SWDIO)
/TX: U4.2 (P1.09); also elsewhere on the board
/nRESET: J1.3 (~RESET), R17.1, U4.20 (NRESET)
GND: C14.2, J1.5 (GND), J2.2, R14.2, R19.2, U4.1 (GND), U4.13 (GND); also elsewhere on the board
unnamed: R10.2, R14.1, U4.12 (P1.04/AIN0)

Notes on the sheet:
MAIN

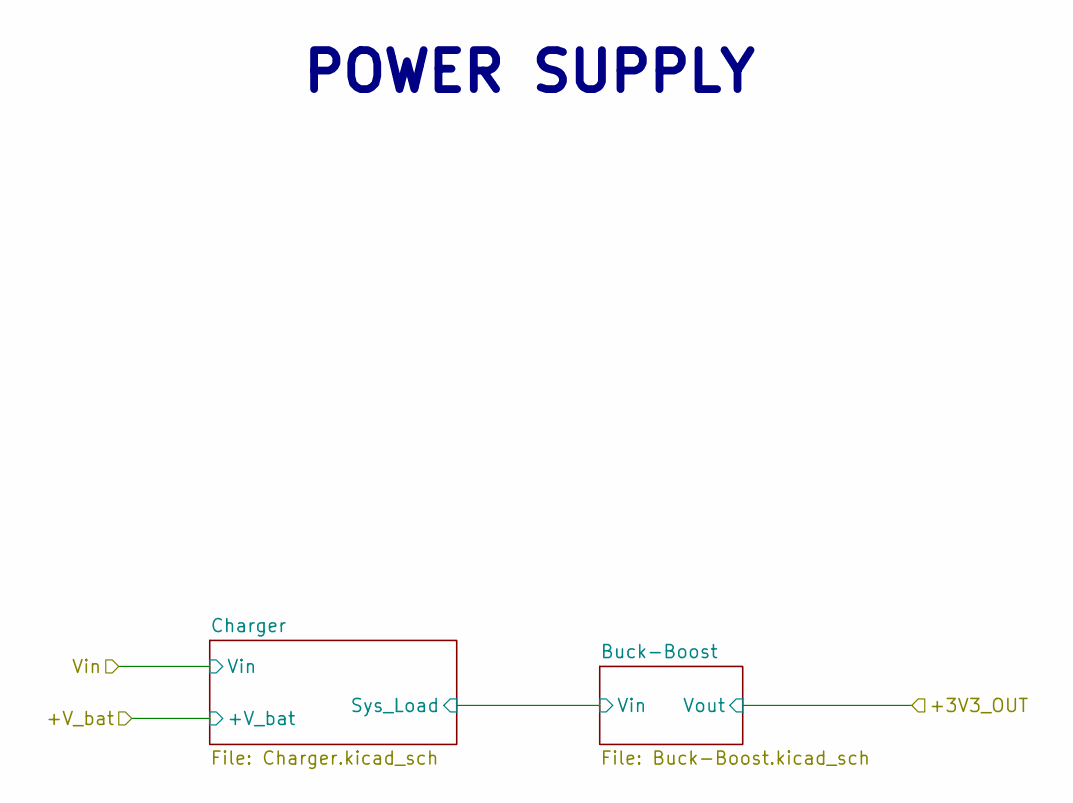
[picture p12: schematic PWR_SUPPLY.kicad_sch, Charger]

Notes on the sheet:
POWER SUPPLY

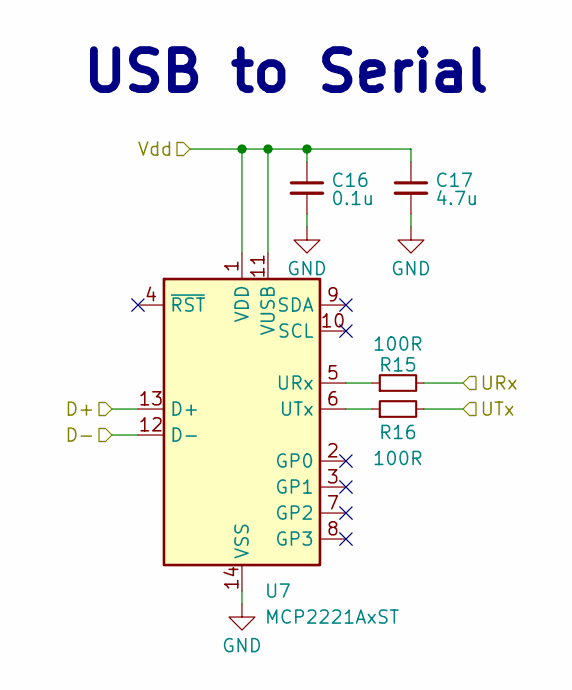
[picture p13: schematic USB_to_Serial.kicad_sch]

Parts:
C16: 0.1u; C_0603_1608Metric
C17: 4.7u; C_0805_2012Metric
R15, R16: 100R; R_0603_1608Metric
U7: MCP2221AxST; TSSOP-14_4.4x5mm_P0.65mm

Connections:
+3V3: C16.1, C17.1, U7.1 (VDD), U7.11 (VUSB); also elsewhere on the board
/RX: R16.2; also elsewhere on the board
/TX: R15.2; also elsewhere on the board
/usb-c/Protected_D+: U7.13 (D+); also elsewhere on the board
/usb-c/Protected_D-: U7.12 (D-); also elsewhere on the board
GND: C16.2, C17.2, U7.14 (VSS); also elsewhere on the board
unnamed: R15.1, U7.5 (URx)
unnamed: R16.1, U7.6 (UTx)

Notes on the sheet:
USB to Serial

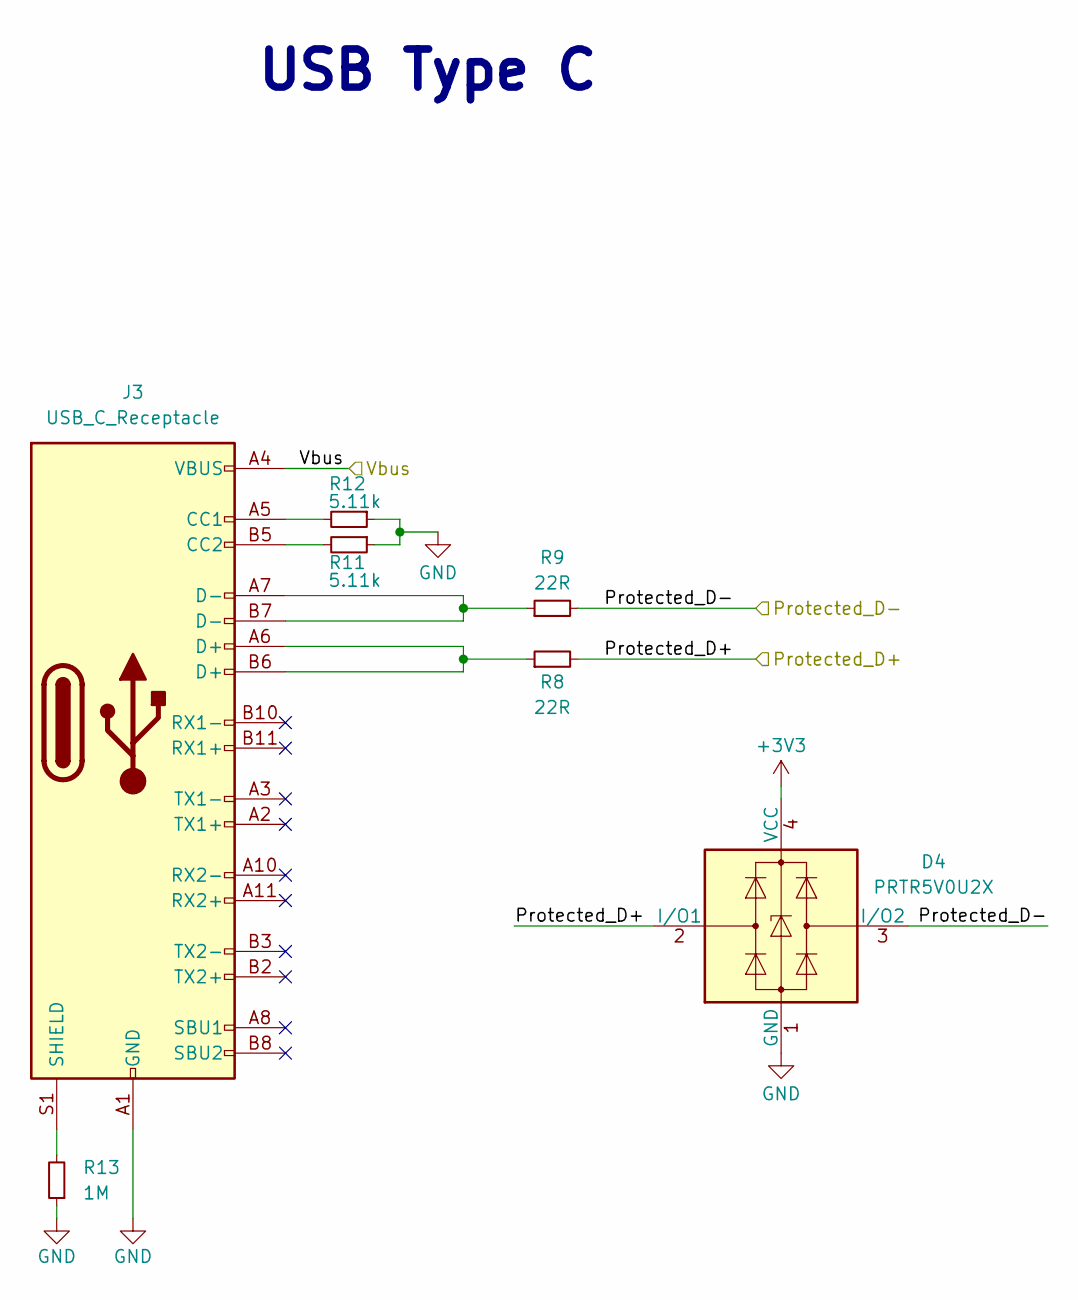
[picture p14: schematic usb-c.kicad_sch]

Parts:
D4: PRTR5V0U2X; SOT-143
J3: USB_C_Receptacle; USB_C_Receptacle_G-Switch_GT-USB-7010ASV
R8, R9: 22R; R_0603_1608Metric
R11, R12: 5.11k; R_0603_1608Metric
R13: 1M; R_0603_1608Metric

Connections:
+3V3: D4.4 (VCC); also elsewhere on the board
+5V: J3.A4 (VBUS), J3.A9 (VBUS), J3.B4 (VBUS), J3.B9 (VBUS); also elsewhere on the board
/usb-c/Protected_D+: D4.2 (I/O1), R8.2; also elsewhere on the board
/usb-c/Protected_D-: D4.3 (I/O2), R9.2; also elsewhere on the board
GND: D4.1 (GND), J3.A1 (GND), J3.A12 (GND), J3.B1 (GND), J3.B12 (GND), R11.1, R12.1, R13.1; also elsewhere on the board
unnamed: J3.A5 (CC1), R12.2
unnamed: J3.B5 (CC2), R11.2
unnamed: J3.A6 (D+), J3.B6 (D+), R8.1
unnamed: J3.A7 (D-), J3.B7 (D-), R9.1
unnamed: J3.S1 (SHIELD), R13.2

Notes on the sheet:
USB Type C

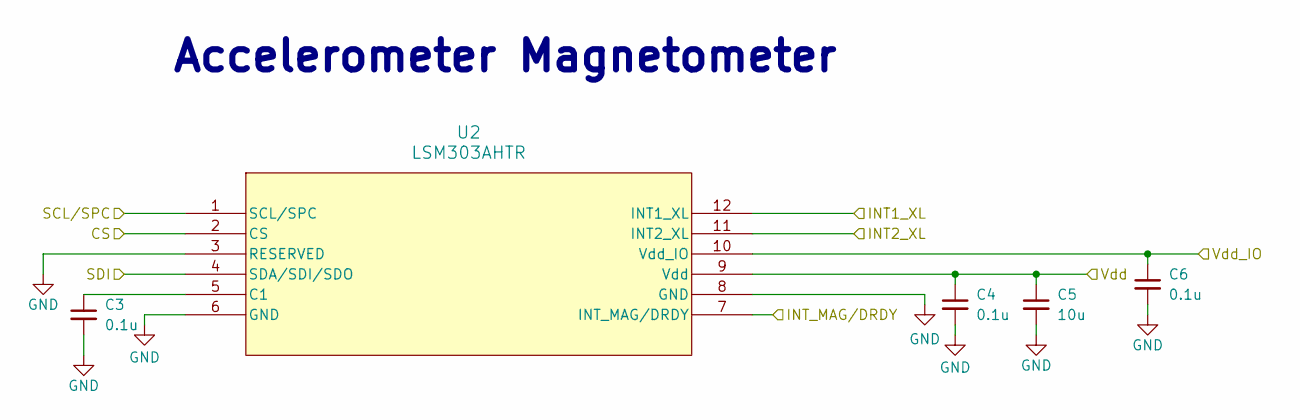
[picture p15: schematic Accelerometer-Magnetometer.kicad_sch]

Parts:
C3, C4, C6: 0.1u; C_0603_1608Metric
C5: 10u; C_0805_2012Metric
U2: LSM303AHTR

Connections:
+3V3: C4.1, C5.1, C6.1, U2.9 (Vdd), U2.10 (Vdd_IO); also elsewhere on the board
/INT1_XL: U2.12 (INT1_XL); also elsewhere on the board
/INT2_XL: U2.11 (INT2_XL); also elsewhere on the board
/INT_MAG/DRDY: U2.7 (INT_MAG/DRDY); also elsewhere on the board
/MISO: U2.4 (SDA/SDI/SDO); also elsewhere on the board
/SPC: U2.1 (SCL/SPC); also elsewhere on the board
GND: C3.2, C4.2, C5.2, C6.2, U2.2 (CS), U2.3 (RESERVED), U2.6 (GND), U2.8 (GND); also elsewhere on the board
unnamed: C3.1, U2.5 (C1)

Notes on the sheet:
Accelerometer Magnetometer

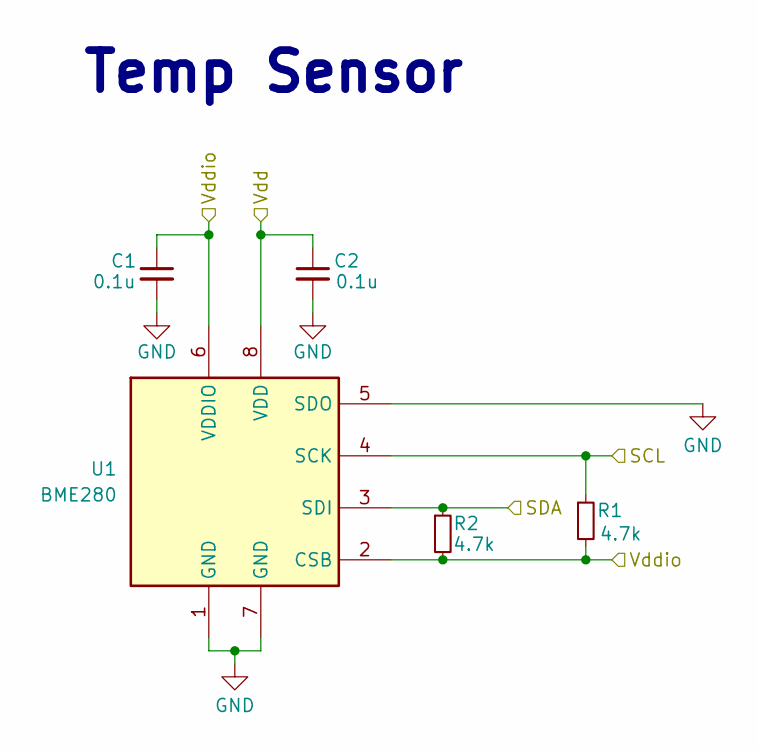
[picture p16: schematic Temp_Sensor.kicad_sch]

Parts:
C1, C2: 0.1u; C_0603_1608Metric
R1, R2: 4.7k; R_0603_1608Metric
U1: BME280; Bosch_LGA-8_2.5x2.5mm_P0.65mm_ClockwisePinNumbering

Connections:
+3V3: C1.1, C2.1, R1.2, R2.2, U1.2 (CSB), U1.6 (VDDIO), U1.8 (VDD); also elsewhere on the board
/SCL: R1.1, U1.4 (SCK); also elsewhere on the board
/SDA: R2.1, U1.3 (SDI); also elsewhere on the board
GND: C1.2, C2.2, U1.1 (GND), U1.5 (SDO), U1.7 (GND); also elsewhere on the board

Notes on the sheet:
Temp Sensor

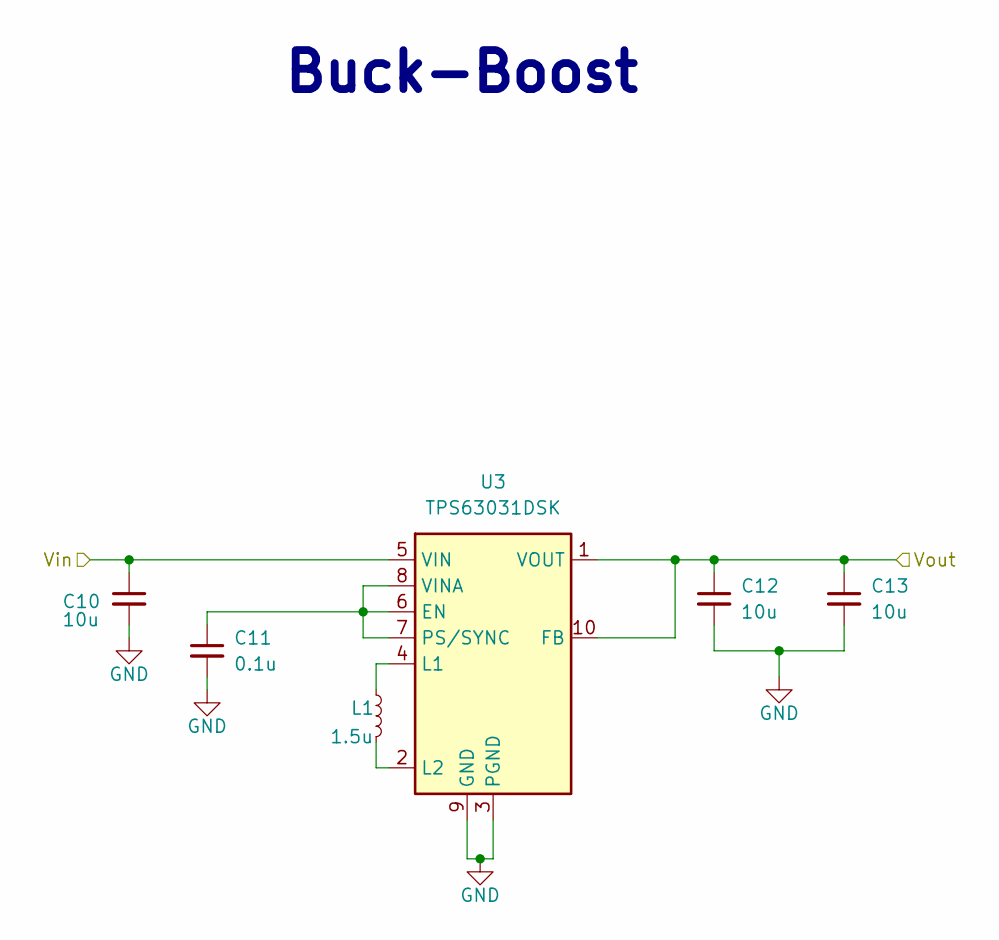
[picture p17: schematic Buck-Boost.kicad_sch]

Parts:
C10, C12, C13: 10u; C_0805_2012Metric
C11: 0.1u; C_0603_1608Metric
L1: 1.5u; L_1210_3225Metric
U3: TPS63031DSK; WSON-10-1EP_2.5x2.5mm_P0.5mm_EP1.2x2mm

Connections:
+3V3: C12.1, C13.1, U3.1 (VOUT), U3.10 (FB); also elsewhere on the board
/PWR_SUPPLY/Buck-Boost/Vin: C10.1, U3.5 (VIN); also elsewhere on the board
GND: C10.2, C11.2, C12.2, C13.2, U3.3 (PGND), U3.9 (GND), U3.11 (PGND); also elsewhere on the board
unnamed: C11.1, U3.6 (EN), U3.7 (PS/SYNC), U3.8 (VINA)
unnamed: L1.1, U3.4 (L1)
unnamed: L1.2, U3.2 (L2)

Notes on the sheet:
Buck-Boost

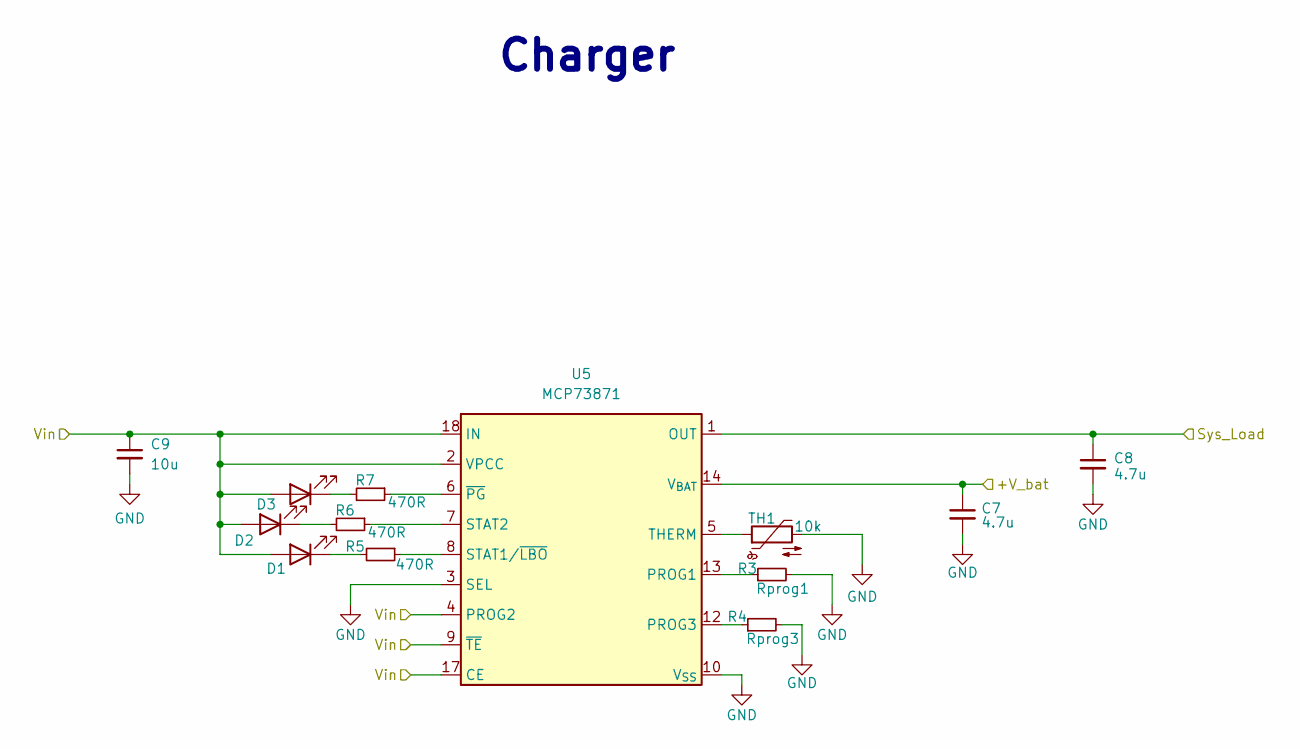
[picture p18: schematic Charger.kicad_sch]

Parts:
C7, C8: 4.7u; C_0603_1608Metric
C9: 10u; C_0603_1608Metric
D1, D2, D3: LED; LED_0603_1608Metric
R3: Rprog1; R_0603_1608Metric
R4: Rprog3; R_0603_1608Metric
R5, R6, R7: 470R; R_0603_1608Metric
TH1: 10k; R_0603_1608Metric
U5: MCP73871; QFN-20-1EP_4x4mm_P0.5mm_EP2.5x2.5mm

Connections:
+5V: C9.1, D1.2 (A), D2.2 (A), D3.2 (A), U5.2 (VPCC), U5.4 (PROG2), U5.9 (~TE), U5.17 (CE), U5.18 (IN), U5.19 (IN); also elsewhere on the board
+V_bat: C7.1, U5.14 (V_{BAT}), U5.15 (V_{BAT}), U5.16 (V_{BAT_SENSE}); also elsewhere on the board
/PWR_SUPPLY/Buck-Boost/Vin: C8.1, U5.1 (OUT), U5.20 (OUT); also elsewhere on the board
GND: C7.2, C8.2, C9.2, R3.2, R4.2, TH1.2, U5.3 (SEL), U5.10 (V_{SS}), U5.11 (V_{SS}), U5.21 (V_{SS}); also elsewhere on the board
unnamed: D1.1 (K), R5.2
unnamed: D2.1 (K), R6.2
unnamed: D3.1 (K), R7.2
unnamed: R3.1, U5.13 (PROG1)
unnamed: R4.1, U5.12 (PROG3)
unnamed: R5.1, U5.8 (STAT1/~LBO)
unnamed: R6.1, U5.7 (STAT2)
unnamed: TH1.1, U5.5 (THERM)
unnamed: R7.1, U5.6 (~PG)

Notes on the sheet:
Charger

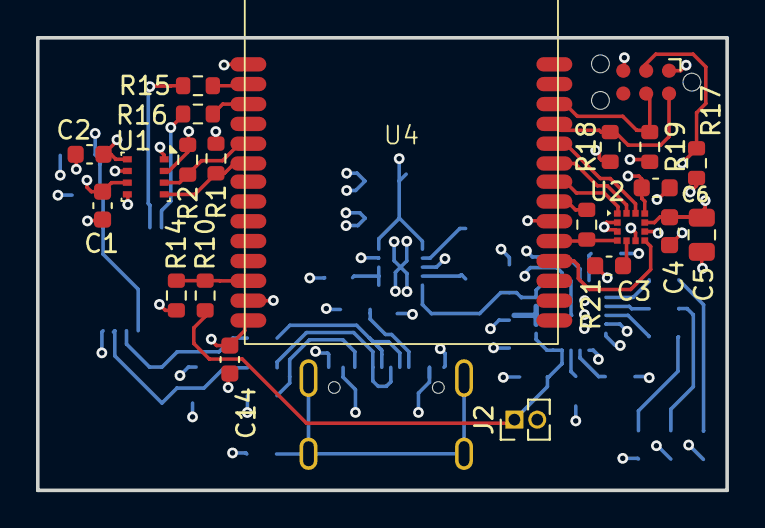
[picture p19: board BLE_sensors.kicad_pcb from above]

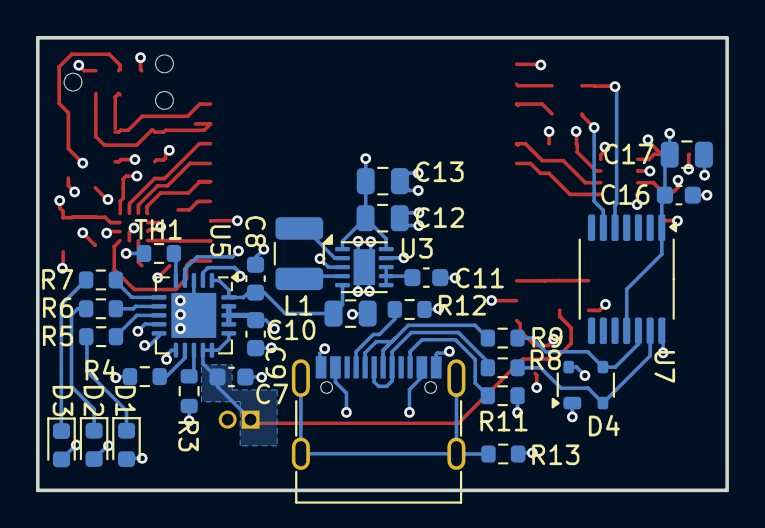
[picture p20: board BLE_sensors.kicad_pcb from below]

Board: 4 copper layers, 38.3 x 25.1 mm, 51 parts (29 on the bottom side), 41 nets.

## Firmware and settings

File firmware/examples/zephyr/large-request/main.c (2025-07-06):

/*
 * Copyright (c) Blecon Ltd
 * SPDX-License-Identifier: Apache-2.0
 */

#include <zephyr/kernel.h>
#include <zephyr/sys/printk.h>
#include <zephyr/shell/shell.h>

#include "stdio.h"
#include "string.h"
#include "stdlib.h"

#include "blecon/blecon.h"
#include "blecon/blecon_error.h"
#include "blecon_zephyr/blecon_zephyr.h"
#include "blecon_zephyr/blecon_zephyr_event_loop.h"

#define CONCURRENT_SEND_OPS_COUNT 2

struct example_send_op_t {
    struct blecon_request_send_data_op_t op;
    bool busy;
};

static struct blecon_event_loop_t* _event_loop = NULL;
static struct blecon_t _blecon = {0};
static struct blecon_request_t _request = {0};
static struct example_send_op_t _send_ops[CONCURRENT_SEND_OPS_COUNT] = {0};
static struct blecon_request_receive_data_op_t _receive_op = {0};
static uint8_t _outgoing_data_buffer[CONFIG_LARGE_REQUEST_EXAMPLE_BUFFER_SZ] = {0}; // Large buffer
static size_t _outgoing_data_buffer_pos = 0;
static uint8_t _incoming_data_buffer[64] = {0};

// Blecon callbacks
static void example_on_connection(struct blecon_t* blecon);
static void example_on_disconnection(struct blecon_t* blecon);
static void example_on_time_update(struct blecon_t* blecon);
static void example_on_ping_result(struct blecon_t* blecon);

const static struct blecon_callbacks_t blecon_callbacks = {
    .on_connection = example_on_connection,
    .on_disconnection = example_on_disconnection,
    .on_time_update = example_on_time_update,
    .on_ping_result = example_on_ping_result
};

// Requests callbacks
static void example_request_on_closed(struct blecon_request_t* request);
static void example_request_on_data_sent(struct blecon_request_send_data_op_t* send_data_op, bool data_sent);
static uint8_t* example_request_alloc_incoming_data_buffer(struct blecon_request_receive_data_op_t* receive_data_op, size_t sz);
static void example_request_on_data_received(struct blecon_request_receive_data_op_t* receive_data_op, bool data_received, const uint8_t* data, size_t sz, bool finished);

const static struct blecon_request_callbacks_t blecon_request_callbacks = {
    .on_closed = example_request_on_closed,
    .on_data_sent = example_request_on_data_sent,
    .alloc_incoming_data_buffer = example_request_alloc_incoming_data_buffer,
    .on_data_received = example_request_on_data_received
};

// Internal functions
static void example_send_data(void);

// Shell commands
static int cmd_blecon_connection_initiate(const struct shell* sh, size_t argc, char** argv);
static int cmd_blecon_send_data(const struct shell* sh, size_t argc, char** argv);
static int cmd_blecon_announce(const struct shell* sh, size_t argc, char** argv);

// Shell command event handlers
static void cmd_blecon_connection_initiate_event(struct blecon_event_t* event, void* user_data);
static void cmd_blecon_send_data_event(struct blecon_event_t* event, void* user_data);
static void cmd_blecon_announce_event(struct blecon_event_t* event, void* user_data);

// Event handler ids
static struct blecon_event_t* _cmd_blecon_connection_initiate_event = NULL;
static struct blecon_event_t* _cmd_blecon_send_data_event = NULL;
static struct blecon_event_t* _cmd_blecon_announce_event = NULL;

static void send_data(struct blecon_t* blecon) {
    printk("Connected, sending request.\r\n");

    // Clean-up request
    blecon_request_cleanup(&_request);
    
    // Reset outgoing buffer position
    _outgoing_data_buffer_pos = 0;

    // Reset send operations
    for(size_t p = 0; p < CONCURRENT_SEND_OPS_COUNT; p++) {
        _send_ops[p].busy = false;
    }
    
    // Queue initial send operations
    example_send_data();

    // Create receive data operation
    if(!blecon_request_receive_data(&_receive_op, &_request, NULL)) {
        printk("Failed to receive data\r\n");
        blecon_request_cleanup(&_request);
        return;
    }

    // Submit request
    blecon_submit_request(&_blecon, &_request);
}

void example_on_connection(struct blecon_t* blecon) {
    send_data(blecon);
}

void example_on_disconnection(struct blecon_t* blecon) {
    printk("Disconnected\r\n");
}

void example_on_time_update(struct blecon_t* blecon) {
    printk("Time update\r\n");
}

void example_on_ping_result(struct blecon_t* blecon) {}

void example_request_on_data_received(struct blecon_request_receive_data_op_t* receive_data_op, bool data_received, const uint8_t* data, size_t sz, bool finished) {
    // Retrieve response
    if(!data_received) {
        printk("Failed to receive data\r\n");
        return;
    }
    printk("Data received\r\n");

    if(finished) {
        printk("All received\r\n");
    }
}

void example_request_on_data_sent(struct blecon_request_send_data_op_t* send_data_op, bool data_sent) {
    // Mark send operation as not busy
    struct example_send_op_t* op = (struct example_send_op_t*)blecon_request_send_data_op_get_user_data(send_data_op);
    op->busy = false;

    if(!data_sent) {
        printk("Failed to send data\r\n");
        return;
    }
    printk("Data sent\r\n");

    // Send more chunks if needed
    example_send_data();
}

uint8_t* example_request_alloc_incoming_data_buffer(struct blecon_request_receive_data_op_t* receive_data_op, size_t sz) {
    return _incoming_data_buffer;
}

void example_request_on_closed(struct blecon_request_t* request) {
    enum blecon_request_status_code_t status_code = blecon_request_get_status(request);

    if(status_code != blecon_request_status_ok) {
        printk("Request failed with status code: %d\r\n", status_code);
    } else {
        printk("Request successful\r\n");
    }

    // Terminate connection
    blecon_connection_terminate(&_blecon);
}

void example_send_data(void) {
    for(size_t p = 0; p < CONCURRENT_SEND_OPS_COUNT; p++) {
        struct example_send_op_t* op = &_send_ops[p];
        if(op->busy) {
            continue;
        }
        op->busy = true;

        if(_outgoing_data_buffer_pos >= sizeof(_outgoing_data_buffer)) {
            // Already finished
            break;
        }

        size_t chunk_sz = 4096;
        if(_outgoing_data_buffer_pos + chunk_sz > sizeof(_outgoing_data_buffer)) {
            chunk_sz = sizeof(_outgoing_data_buffer) - _outgoing_data_buffer_pos;
        }

        bool finished = false;
        if(_outgoing_data_buffer_pos + chunk_sz >= sizeof(_outgoing_data_buffer)) {
            finished = true;
        }

        printk("Sending chunk of %u bytes\r\n", chunk_sz);

        // Create send data operation
        if(!blecon_request_send_data(&op->op, &_request, _outgoing_data_buffer + _outgoing_data_buffer_pos, chunk_sz, finished, op)) {
            printk("Failed to send data\r\n");
            blecon_request_cleanup(&_request);
            return;
        }

        _outgoing_data_buffer_pos += chunk_sz;

        if(finished) {
            printk("All sent\r\n");
            break;
        }
    }
}

int main(void)
{
#if defined(CONFIG_USB_CDC_ACM)
    // Give a chance to UART to connect
    k_sleep(K_MSEC(1000));
#endif

    // Set up the _outgoing_data_buffer with a known pattern
    for(size_t p = 0; p < sizeof(_outgoing_data_buffer); p++) {
        _outgoing_data_buffer[p] = (uint8_t)p;
    }

    // Get event loop
    _event_loop = blecon_zephyr_get_event_loop();

    // Get modem
    struct blecon_modem_t* modem = blecon_zephyr_get_modem();

    // Register event ids for shell commands
    _cmd_blecon_connection_initiate_event = blecon_event_loop_register_event(_event_loop, cmd_blecon_connection_initiate_event, NULL);
    _cmd_blecon_send_data_event = blecon_event_loop_register_event(_event_loop, cmd_blecon_send_data_event, NULL);
    _cmd_blecon_announce_event = blecon_event_loop_register_event(_event_loop, cmd_blecon_announce_event, NULL);

    // Blecon
    blecon_init(&_blecon, modem);
    blecon_set_callbacks(&_blecon, &blecon_callbacks, NULL);
    if(!blecon_setup(&_blecon)) {
        printk("Failed to setup blecon\r\n");
        return 1;
    }

    // Init request
    const static struct blecon_request_parameters_t request_params = {
        .namespace = "mynamespace",
        .method = "upload",
        .oneway = true,
        .request_content_type = NULL,
        .response_content_type = NULL,
        .response_mtu = sizeof(_incoming_data_buffer),
        .callbacks = &blecon_request_callbacks,
        .user_data = NULL
    };
    blecon_request_init(&_request, &request_params);

    // Print device URL
    char blecon_url[BLECON_URL_SZ] = {0};
    if(!blecon_get_url(&_blecon, blecon_url, sizeof(blecon_url))) {
        printk("Failed to get device URL\r\n");
        return 1;
    }
    printk("Device URL: %s\r\n", blecon_url);

    // Initiate connection
    if(!blecon_connection_initiate(&_blecon)) {
        printk("Failed to initiate connection\r\n");
        return 1;
    }

    // Enter main loop.
    blecon_event_loop_run(_event_loop);

    // Won't reach here
    return 0;
}

int cmd_blecon_connection_initiate(const struct shell* sh, size_t argc, char** argv) {
    if(_cmd_blecon_connection_initiate_event == NULL) {
        shell_print(sh, "Event id not assigned");
        return -1;
    }
    blecon_event_signal(_cmd_blecon_connection_initiate_event);
    return 0;
}

int cmd_blecon_send_data(const struct shell* sh, size_t argc, char** argv) {
    if(_cmd_blecon_send_data_event == NULL) {
        shell_print(sh, "Event id not assigned");
        return -1;
    }
    blecon_event_signal(_cmd_blecon_send_data_event);
    return 0;
}

int cmd_blecon_announce(const struct shell* sh, size_t argc, char** argv) {
    if(_cmd_blecon_announce_event == NULL) {
        shell_print(sh, "Event id not assigned");
        return -1;
    }
    blecon_event_signal(_cmd_blecon_announce_event);
    return 0;
}

void cmd_blecon_connection_initiate_event(struct blecon_event_t* event, void* user_data) {
    // Initiate connection
    if(!blecon_connection_initiate(&_blecon)) {
        printk("Failed to initiate connection\r\n");
        return;
    }
}

void cmd_blecon_send_data_event(struct blecon_event_t* event, void* user_data) {
    // If we are already connected, send data immediately
    if(blecon_is_connected(&_blecon)) {
        send_data(&_blecon);
        return;
    } else {
        // Initiate connection - send_data will be called by example_on_connection when connected
        if(!blecon_connection_initiate(&_blecon)) {
            printk("Failed to initiate connection\r\n");
            return;
        }
    }
}

void cmd_blecon_announce_event(struct blecon_event_t* event, void* user_data) {
    // Announce device ID
    if(!blecon_announce(&_blecon)) {
        printk("Failed to announce device ID\r\n");
        return;
    }
}


SHELL_STATIC_SUBCMD_SET_CREATE(blecon,
	SHELL_CMD(connection_initiate, NULL, "Initiate connection to Blecon network.", cmd_blecon_connection_initiate),
    SHELL_CMD(send_data, NULL, "Send data to Blecon network.", cmd_blecon_send_data),
    SHELL_CMD(announce, NULL, "Announce Blecon device ID to nearby hotspots.", cmd_blecon_announce),
    SHELL_SUBCMD_SET_END
);
SHELL_CMD_REGISTER(blecon, &blecon, "Blecon commands", NULL);

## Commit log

2025-03-09 Added accelerometer datasheet
2025-03-09 Added models for temp sensor and accelerometer
2025-03-09 changes in parts models
    [LGA_3AHTR_STM.step]
2025-03-09 Added lsm303
    [BLE_sensors.kicad_pcb, BLE_sensors.kicad_sch]
2025-03-09 added BM15C
    [BLE_sensors.kicad_pcb, BLE_sensors.kicad_sch]
2025-04-27 added datashet for me54bs01 and dev board and the me54bs01 to the kicad project
    [BLE_sensors.kicad_pcb, BLE_sensors.kicad_sch]
2025-06-01 Refactor schematic and added power supplpy
    [BLE_sensors.kicad_pcb, BLE_sensors.kicad_sch, Buck-Boost.kicad_sch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]
2025-06-02 Added the usb to serial bridge
    [Accelerometer-Magnetometer.kicad_sch, BLE_sensors.kicad_sch, Charger.kicad_sch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]
2025-06-02 Added schematic
    [BLE_sensors.kicad_pcb]
2025-06-03 Footprints and some pcb placement
    [Accelerometer-Magnetometer.kicad_sch, BLE_sensors.kicad_pcb, BLE_sensors.kicad_sch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]
2025-06-05 Initial pcb placement
    [BLE_sensors.kicad_pcb, BLE_sensors.kicad_sch, Charger.kicad_sch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]
2025-06-07 Added layers
    [BLE_sensors.kicad_pcb]
2025-06-09 PCB rev1
    [Accelerometer-Magnetometer.kicad_sch, BLE_sensors.kicad_pcb]
2025-06-10 Changed bme power supply and added pull up to tag connect
    [BLE_sensors.kicad_pcb, BLE_sensors.kicad_sch, PWR_SUPPLY.kicad_sch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]
2025-06-13 Added a capasitor to me54bs01 pwr supply and added gerbers and schematic
    [Accelerometer-Magnetometer.kicad_sch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]
2025-06-14 Added BOM
    [BLE_sensors_BOM.xlsx]
2025-06-19 changes in BOM orders
    [BLE_sensors_BOM.xlsx]
2025-06-26 excel change
    [BLE_sensors_BOM.xlsx]
2025-07-03 fixed spi
    [BLE_sensors.kicad_pcb, BLE_sensors.kicad_sch, BLE_sensors_BOM.xlsx]
2025-07-06 added firmware file
    [LGA_3AHTR_STM.step]
2025-10-17 Added pdf
    [Accelerometer-Magnetometer.kicad_sch, BLE_sensors.kicad_pcb, BLE_sensors.kicad_sch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]
2025-10-17 added presentation flowchart
2025-10-20 Add flowchart for reflector small flowchart setup and operation
    - Introduced a flowchart diagram in Mermaid syntax to illustrate the setup and operational flow of the reflector system.
    - Included key stages such as initialization, data advertisement loop, channel sounding, and power management.
    - Enhanced clarity on the system's behavior during motion detection and sleep states.
2025-11-30 Add README for BLE Sensor PCB project
    This README provides an overview of the BLE Sensor PCB project, including its contents and purpose.
